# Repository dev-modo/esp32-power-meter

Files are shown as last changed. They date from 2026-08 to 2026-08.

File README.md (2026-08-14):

# ESP32 Power Meter

A complete home power-monitoring system: an **ESP32** reads a **PZEM-004T (100 A)** energy-meter module and pushes readings once a second to a small **Python (FastAPI) backend** running on your home server. A static **dashboard hosted on GitHub Pages** pulls the data from that backend and shows live values and history graphs for every metric.

```mermaid
flowchart LR
    PZEM[PZEM-004T 100A] -- "Modbus-RTU (UART)" --> ESP[ESP32]
    ESP -- "HTTP POST /api/ingest\nevery 1 s" --> API[FastAPI backend\nhome server :8000]
    API -- "SQLite" --> DB[(readings.db)]
    WEB[Dashboard\nGitHub Pages] -- "GET /api/latest\nGET /api/history\nGET /api/stats" --> API
```

## Repository layout

| Directory | What it is |
|---|---|
| [`firmware/`](firmware/) | ESP32 firmware (PlatformIO / Arduino IDE) — PZEM readings, WiFiManager pairing, status LED, reset button |
| [`server/`](server/) | Python FastAPI backend — receives readings, stores them in SQLite, serves the dashboard API (Docker Compose ready) |
| [`docs/`](docs/) | Static dashboard — served by GitHub Pages, shows live tiles + history charts for all metrics |
| [`enclosure/`](enclosure/) | 3D-printable box and screw-on lid (OpenSCAD source + ready-to-slice STLs) |

## Hardware

- ESP32 dev board (any common devkit)
- PZEM-004T **100 A** module (external CT coil version; Modbus-RTU protocol)
- 1 LED (status indicator — the onboard LED on GPIO 2 works out of the box)
- 1 push button (WiFi reset / pairing)

| PZEM-004T | ESP32 |
|---|---|
| TX | GPIO 16 (RX2) |
| RX | GPIO 17 (TX2) |
| VCC | 5 V (VIN) |
| GND | GND |

| Part | ESP32 |
|---|---|
| LED (+ 220 Ω to GND) | GPIO 2 |
| Push button (to GND) | GPIO 13 |

**LED codes:** fast blink = pairing portal open · medium blink = connecting to WiFi · solid = connected and server reachable · slow blink = WiFi OK but server unreachable.

**Button:** hold **5 seconds** to erase WiFi credentials and reboot into pairing mode (`PowerMeter-Setup` access point).

## Mains electricity — read before you build

This device connects to **230 V AC mains**. Mains voltage can kill you, and a
fault inside a badly built monitor can start a fire inside your wall.

**The 3D-printed enclosure in [`enclosure/`](enclosure/) is a bench and
prototyping housing. It is not a certified mains enclosure and must not be used
for a permanent, unattended installation.** Hobby filament has no UL 94
flammability rating, no tracking rating and no glow-wire rating. For anything
permanent, use an off-the-shelf ABS or PC IP65 junction box.

At minimum, if you build this:

- **Never print the enclosure in PLA** — PETG at minimum, V-0 rated ideally
- **Fuse the voltage tap**: inline 500 mA–1 A *ceramic* HRC fuse, 250 V AC, in
  the live sense lead; feed it from a fused spur or MCB way behind a 30 mA RCD
- Use a **PZEM-004T v3.0 or v4.0** — earlier revisions lack opto-isolated TTL
  and would put the ESP32 and its USB port at mains potential
- **Never connect USB while the mains side is live**, and flash the firmware
  with mains fully disconnected
- Use **cable glands**, not bare holes, and separate the mains and low-voltage
  sides inside the box
- The CT clamps **one conductor only**, never live and neutral together

Full detail in [`enclosure/README.md`](enclosure/README.md#mains-safety). If you
are not confident working with mains, have an electrician do the connection.

## Getting started

Set things up in this order:

### 1. Backend (home server)

```bash
cd server
cp .env.example .env   # set your API key
docker compose up -d
```

The API listens on port **8000**. See [`server/README.md`](server/README.md) — including the important **HTTPS / mixed-content** section: GitHub Pages is served over HTTPS, so the browser will only call your backend if it is also reachable over HTTPS (e.g. behind Nginx Proxy Manager with a DuckDNS domain and Let's Encrypt).

### 2. Firmware (ESP32)

Flash `firmware/` with PlatformIO or the Arduino IDE, then power up. The ESP32 opens a `PowerMeter-Setup` access point — join it, and in the portal pick your WiFi and enter the backend URL, API key, and device ID. Full walkthrough in [`firmware/README.md`](firmware/README.md).

### 3. Dashboard

The dashboard is published automatically from `docs/` via GitHub Pages. Open it, tap the gear icon, and enter your backend URL. Settings are stored locally in your browser.

## Try it without hardware

[`tools/mock_esp32.py`](tools/mock_esp32.py) simulates the whole device — a house with a fridge cycling, a kettle spiking, lights and AC switching on and off — and posts the exact same payload the firmware does. Stdlib only, no dependencies.

```bash
# Terminal 1 — the backend
cd server && API_KEY=demo-key-12345 \
  DB_PATH=./data/powermeter.db uvicorn main:app --port 8000

# Terminal 2 — seed 6 h of history, then stream live every 1 s
python3 tools/mock_esp32.py --backfill 6 --key demo-key-12345
```

Open `docs/index.html` (or the hosted dashboard) and point it at `http://localhost:8000`. About 1% of readings are sent as nulls on purpose, simulating a failed PZEM read, so the chart gap handling gets exercised too.

## Exposing a local backend

GitHub Pages is HTTPS, so the dashboard can only reach an HTTPS backend. To demo from a laptop, tunnel it:

```bash
# ngrok — needs a free account authtoken, one time
ngrok config add-authtoken YOUR_TOKEN
ngrok http 8000

# or Cloudflare quick tunnel — no account needed
cloudflared tunnel --url http://localhost:8000
```

Paste the resulting HTTPS URL into the dashboard's settings panel, or set `DEFAULT_BASE_URL` at the top of [`docs/app.js`](docs/app.js) to bake it in.

> Both of the above hand out a **random URL that changes on every restart**. For something permanent, use an ngrok static domain (one is included free), or a named Cloudflare tunnel on a domain you own. For a real always-on install, the intended setup is the backend on your home server behind a reverse proxy with a Let's Encrypt certificate — see [`server/README.md`](server/README.md).

## API overview

| Endpoint | Purpose |
|---|---|
| `POST /api/ingest` | ESP32 pushes a reading (voltage, current, power, energy, frequency, power factor, RSSI, uptime) |
| `GET /api/latest` | Most recent reading + online flag |
| `GET /api/history?minutes=&max_points=` | Downsampled time series for charts |
| `GET /api/stats?hours=` | Energy used, average/max power, voltage range over a window |
| `GET /api/health` | Health check |

## License

[MIT](LICENSE)

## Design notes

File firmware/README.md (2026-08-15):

# ESP32 Power Meter — Firmware

Firmware for an ESP32 devkit that reads a **PZEM-004T (100 A, Modbus-RTU)**
energy monitor every **second** and POSTs the readings as JSON to the
project's ingest server (`POST <server_url>/api/ingest`). WiFi and server
settings are configured through a captive pairing portal — no code edits or
reflashing needed to change networks or servers.

> **⚠️ Mains voltage warning:** the PZEM-004T's measurement side connects to
> live mains wiring. If you are not comfortable and qualified to work with
> mains voltage, get help from someone who is. Always kill the breaker before
> touching the high-voltage side.

## Wiring

The PZEM has **two electrically separate sides** at opposite ends of the board.
Only the 4-pin header touches the ESP32. The screw terminals are mains.

### Low-voltage side: the 4-pin header → ESP32

The header is labelled, in order, **GND · TX · RX · 5V**. Trust the silkscreen
text rather than counting pins — clone boards have been seen rotated.

| PZEM header | ESP32 | Notes |
|---|---|---|
| GND | GND | Mandatory. Without it the opto interface cannot work at all. |
| **TX** | **GPIO4** | ⚠️ Note the cross-over — PZEM *TX* goes to the ESP32 pin that *receives* |
| **RX** | **GPIO25** | ⚠️ PZEM *RX* goes to the ESP32 pin that *transmits* |
| 5V | **3V3** ← *not* 5V | See the box below. This pin only feeds the optocoupler LEDs. |

9600 baud, 8N1, Modbus-RTU.

> [!IMPORTANT]
> **The data pair crosses over. TX does not go to TX.**
>
> ```
>   PZEM  TX ──────────────╮   ╭────────── GPIO4   (ESP32 receives)
>                          ╰─╳─╯
>   PZEM  RX ──────────────╯   ╰────────── GPIO25  (ESP32 transmits)
> ```
>
> "TX" printed on a board always means *that board's* transmit pin, so the label
> is relative to whichever board you are reading. TX is a mouth, RX is an ear —
> each device's mouth has to point at the other's ear. Wiring TX→TX puts two
> mouths together and leaves both ears listening to each other.
>
> **Getting it wrong causes no damage**, it just means silence: every register
> reads `NAN` and the serial log prints `[pzem] no response`. Swap the two data
> wires and it works. Leave GND and the 3V3 supply alone.

Both data pins are named from the ESP32's side in the firmware — `PIN_UART_RX`
is the pin the *ESP32* receives on, so it connects to the PZEM's **TX**.

> [!WARNING]
> **Feed that header's "5V" pin from 3.3 V, not 5 V.** An earlier version of
> this file said to use 5 V and claimed no level shifter was needed. That
> combination is wrong and stresses the ESP32.
>
> The TTL section is nothing but a connector, four 1 kΩ resistors and two
> optocouplers — there is no regulator or level translation on it. The opto
> output is open-collector with **`R4`, a 1 kΩ pull-up to that header pin**, so
> whatever you feed it *becomes the logic level*. At 5 V the PZEM's TX idles at
> 5 V into a GPIO specified for 3.6 V max (ESP32 datasheet Table 5-3,
> V_IH max = VDD + 0.3). The RX line is worse than it looks: its opto LED is fed
> from the same pin through `R8` = 1 kΩ, so whenever GPIO25 is not actively
> pulling low — during reset, before `Serial2` is configured — RX floats to
> ~4.9 V, and the ESP32's internal 45 kΩ pull-down cannot fight a 1 kΩ pull-up.
> So at 5 V *both* pins are over-stressed.
>
> Many people run it at 5 V and report it working: the 1 kΩ limits injected
> current to ~1.4 mA, which parts often survive. That is survival, not
> compliance, and not what you want in a wall for years.
>
> **Powering it from 3.3 V makes both directions natively 3.3 V with no extra
> parts.** The only consequence is less optocoupler current — about 2.1 mA
> instead of 3.8 mA — still ample at 9600 baud, where one bit lasts 104 µs and
> the optocoupler switches in microseconds. If reads are unreliable, solder a
> second 1 kΩ across `R8` to restore ~4.2 mA.
>
> Two honest caveats. This is validated by the module schematic and widely used
> (ESPHome and Tasmota both document it), but it is **not a vendor-sanctioned
> mode** — Peacefair's manual only ever says "requires external 5V power supply"
> and never states a logic level. It fails *safe*: too little opto current gives
> `NAN` reads, never damage. And the board's TX/RX indicator LEDs go dim or dark
> at 3.3 V, so don't diagnose from them.
>
> **If you must use 5 V**, the fix is one resistor, not a level shifter: a
> **1.5 kΩ from the PZEM-TX / GPIO4 node to GND**, which forms a divider with the
> internal 1 kΩ `R4` and lands at 3.00 V. The other direction needs nothing —
> the ESP32's 3.3 V comfortably drives the PZEM's input.

### LED and button

| Peripheral | ESP32 | Notes |
|---|---|---|
| LED | GPIO2 → 220 Ω → LED **anode**; cathode → GND | Active-high. 220 Ω suits red/yellow/green; use 100 Ω for blue/white. The onboard LED on many devkits is already on GPIO2 with its own resistor. |
| Button | GPIO13, other leg → GND | `INPUT_PULLUP`, no external resistor |

GPIO2 is a **download-mode strapping pin**. Wire the LED active-high as above
and it is fine; wiring it active-low or adding a pull-up can break flashing. If
uploads ever turn flaky, disconnecting the GPIO2 LED is the first thing to try.

GPIO13 is also JTAG TCK, which matters only if you ever want hardware debugging
— you would need to unplug the button for that.

### Why GPIO4 / GPIO25 and not the usual GPIO16 / GPIO17

**GPIO16 and GPIO17 are wired to the PSRAM** on every ESP32-WROVER, on
`-N4R2`/`-N8R2`/`-N16R2` WROOM variants, and on PICO-D4. Espressif's DevKitC
guide is blunt: *"The pins GPIO16 and GPIO17 are available for use only on the
boards with the modules ESP32-WROOM and ESP32-SOLO-1. The boards with
ESP32-WROVER modules have the pins reserved for internal use."*

GPIO4 and GPIO25 are free on every variant, and are Espressif's own UART2
defaults from arduino-esp32 3.x onward — changed from 16/17 to *"avoid conflicts
with other peripherals."* The ESP32 routes UART through its GPIO matrix, so any
free pins work. If you have a plain WROOM-32 and prefer 16/17, they will work;
just change `PIN_UART_RX` / `PIN_UART_TX`.

### Powering it

**Use exactly one 5 V source for the ESP32** — either USB or an external supply
into 5V/VIN, never both at once. Some clone devkits omit the protection diode,
and back-feeding the USB rail can damage the board or the host.

### Using an ESP32-C3 instead

Supported — the firmware detects the chip and switches pins itself, so the same
source builds for both. **But the C3 is not a smaller ESP32**, and three facts
from the SDK force a different pinout:

- **`SOC_UART_NUM` is 2.** There is no `Serial2` at all, only `Serial0`/`Serial1`.
- **`SOC_GPIO_PIN_COUNT` is 22.** GPIO25 and GPIO13 simply do not exist.
- **GPIO2, GPIO8 and GPIO9 are strapping pins** (GPIO9 is the BOOT button on most
  devkits), and GPIO18/19 are the USB Serial/JTAG lines.

| | classic ESP32 | ESP32-C3 |
|---|---|---|
| PZEM **TX** → | GPIO4 | **GPIO4** |
| PZEM **RX** → | GPIO25 | **GPIO5** |
| LED | GPIO2 | **GPIO3** |
| Button | GPIO13 | **GPIO10** |
| UART | `Serial2` | `Serial1` |

The PZEM's GND and 3V3 connections are unchanged, and the data pair still
crosses over.

One practical difference: **a C3 devkit's onboard LED is an addressable RGB on
GPIO8**, not a plain one, so `digitalWrite` will not drive it. Wire your own LED
to GPIO3 as in the table.

Build it with `pio run -e esp32c3`, or pick **ESP32C3 Dev Module** in the Arduino
IDE (still set Partition Scheme to Minimal SPIFFS). Verified: **62% flash, 11%
RAM** — it fits comfortably, and uses *less* RAM than the classic ESP32 despite
having less to spare.

## LED status codes

| LED pattern | Meaning |
|---|---|
| Fast blink (150 ms) | Config/pairing portal is active |
| Medium blink (500 ms) | Connecting to WiFi |
| Solid ON | WiFi OK + server reachable |
| Slow blink (1200 ms) | WiFi OK, server unreachable (4+ consecutive failed POSTs)|
| 5 rapid flashes | Factory reset triggered, then reboot into the portal |

## Button

Hold the button for **5 seconds or more** to factory-reset: the LED flashes
5 times rapidly, the **WiFi credentials are erased**, and the device reboots
into the pairing portal. The **server URL, API key and device ID are kept**
in flash (NVS) and show up prefilled in the portal — you only need to pick a
WiFi network again.

## First boot / pairing

1. Power the ESP32. With no WiFi configured, the LED fast-blinks and the
   device opens an **open access point named `PowerMeter-Setup`**.
2. Join `PowerMeter-Setup` from your phone or laptop. A captive portal should
   pop up automatically; if not, browse to **http://192.168.4.1**.
3. Tap **Configure WiFi**, pick your network and enter its password.
4. Fill in the three extra fields:
   - **Server URL** — the **plain `http://` LAN address** of the backend, e.g.
     `http://192.168.1.8:8000`. See the note below — do not put the public
     HTTPS address here.
   - **API key** — leave empty unless the server was started with an `API_KEY`
   - **Device ID** — default `powermeter-01`; change it if you run several meters

> [!IMPORTANT]
> **The server URL is not in the firmware, and the ESP32 does not use the public
> HTTPS address.** Both of those surprise people, so:
>
> **It is not hardcoded** because it lives in NVS instead. You type it once into
> the pairing portal and it survives reboots, reflashes and even a WiFi factory
> reset — so you can move the server or change its port without rebuilding and
> reflashing the firmware.
>
> **It must be `http://`, not `https://`.** This firmware uses plain
> `HTTPClient` with no `WiFiClientSecure`, so it has no TLS at all. Given an
> `https://` URL it simply fails every POST, and the LED sits on the
> server-unreachable slow blink.
>
> That is deliberate, because **the backend has two different consumers with
> different needs**:
>
> | Who | URL | Why |
> |---|---|---|
> | **ESP32** | `http://192.168.1.8:8000` | Same LAN as the server. Talks straight to the container, skipping the reverse proxy. No TLS needed or wanted — it is local traffic, and TLS on an MCU costs flash, RAM and battery for nothing here. |
> | **Dashboard** (browser) | `https://powermeter.dilanp.duckdns.org` | Runs from GitHub Pages over HTTPS, from anywhere. Browsers block an HTTPS page calling a plain-HTTP backend, so this one *must* be TLS, which is what the reverse proxy provides. |
>
> Pointing the ESP32 at the public HTTPS name would also be a needless round
> trip: out to your router, back in through the proxy, to reach a box sitting on
> the same switch.
>
> To report from *outside* your LAN — a remote site on a phone hotspot — put the
> public `https://` URL here instead. The firmware does TLS now; see
> [Remote / cellular operation](#remote--cellular-operation) below, and note the
> interval floor, because data cost is the real constraint there.
5. Save. The device connects (medium blink), then goes **solid ON** once the
   server accepts data. Watch the serial monitor at **115200 baud** for logs.

Settings live in NVS namespace `powermeter`, so they survive reboots and
re-flashes.

## Reconnecting — it never gives up

Once a network has been saved, the firmware **retries it forever and will not
put itself back into pairing mode on its own.** This is deliberate: after a
power cut the router routinely takes a minute or two longer to boot than the
ESP32, and a meter that parks itself in a pairing portal until someone walks
over to it is useless.

| Situation | What happens |
|---|---|
| Saved network not up yet at boot | Retries every ~23 s **indefinitely**, LED medium-blinking. Never opens the portal. |
| WiFi drops while running | `setAutoReconnect` plus a `WiFi.reconnect()` nudge every 15 s, forever. |
| Router gone for a week | Keeps retrying; reconnects on its own when it returns. |
| Saved password no longer correct | Also retries forever — the serial log says `connect failed (wrong password?)` rather than "network not found", so the one user-fixable case is distinguishable. Hold the button to re-pair. |
| Server down but WiFi fine | Keeps posting; LED slow-blinks after 4 failures. Recovers on the first success. |
| No credentials saved (first boot / after reset) | Opens the portal and leaves it open with **no timeout** — there is nothing to retry. |

The only way into pairing mode is to ask for it: **hold the button 5 seconds.**
That works at any time, including while the device is stuck retrying at boot, so
you never need to power-cycle to get the portal back.

Making that guarantee real took some care, and it is the reason the retry loop
calls `WiFi.begin()` directly instead of `wm.autoConnect()`. `autoConnect()`
blocks for the whole connect timeout (~20 s against an absent router) without
reading the button, which left the escape hatch unusable precisely when it was
needed — and worse, a brief tap during that blind window could be mistaken for a
finished hold and wipe the credentials. The connect is now driven by a polled
loop that samples the button every 10 ms, and `handleButton()` additionally
refuses to act on a hold it did not observe continuously. Both directions are
covered by [`test/test_button_logic.py`](test/test_button_logic.py), which runs
on a laptop with no hardware:

```bash
python3 firmware/test/test_button_logic.py    # 12 passed, 0 failed
```

## Remote / cellular operation

The firmware speaks HTTPS, so the meter can live at a remote site on a phone
hotspot and report to the public endpoint. Put the `https://` URL in the portal
and it switches transport automatically.

**Data is the binding constraint, not bandwidth.** Neither ESP32 core supports
TLS session resumption, so any POST on a fresh connection pays a full handshake —
about 4.3 KB, measured against the live server, versus ~700 bytes for the reading
itself. Keep-alive amortises that while the connection survives, but cellular NAT
drops idle connections regularly.

| Interval | Roughly per month |
|---|---|
| 1 s | **~16 GB** — would destroy a phone plan |
| 10 s | ~1.6 GB |
| **30 s** | **~530 MB** — recommended for cellular |
| 60 s | ~265 MB |

So the portal has a **Report interval** field, and the firmware enforces a floor
that follows the transport: **1 s on `http://`**, **10 s on `https://`**. The
clamp is applied at send time, not at save time — move the same device from your
LAN to the remote URL and its cadence backs off on its own. You cannot
accidentally leave it hammering a metered link once a second.

The device reports its own cadence to the server, which sizes the "online" window
from it (3 missed reports + 10 s, floored at 30 s) instead of assuming 10 s. The
dashboard likewise polls at half the device's rate rather than once a second, and
stops entirely while its tab is hidden.

### Things that bite specifically on a hotspot

- **iPhone Personal Hotspot is 5 GHz-only unless "Maximize Compatibility" is on.**
  The ESP32 is 2.4 GHz only, so it will never see the network. Turn that on
  *before* you debug anything else.
- **Certificate validation does not need a clock.** Both cores ship mbedTLS with
  `MBEDTLS_HAVE_TIME_DATE` disabled, so the usual "NTP first or TLS fails" trap
  does not apply — verified in both cores' sdkconfigs. Signature-chain and
  hostname checks still run; only expiry is skipped.
- **The server must keep TLS 1.2 enabled.** Neither core has a TLS 1.3 client, so
  hardening the proxy to 1.3-only would silently kill the device.
- **Two root CAs are embedded**, ISRG Root X1 and X2. Either validates the chain
  today, but each fails in a different future — X1 alone breaks if Let's Encrypt
  stops sending the X2 cross-sign, X2 alone breaks if the cert is re-issued as
  RSA. Both together cost ~2.7 KB.

## Reporting

Every **second** the firmware reads voltage, current, power, cumulative
energy (kWh), frequency and power factor from the PZEM and POSTs them to
`<server_url>/api/ingest` with the `X-API-Key` header (only when a key is
set). Failed sensor reads are sent as JSON `null`. Example payload:

```json
{
  "device_id": "powermeter-01",
  "voltage": 231.2,
  "current": 1.234,
  "power": 285.1,
  "energy": 12.345,
  "frequency": 50.0,
  "pf": 0.95,
  "rssi": -61,
  "uptime_s": 12345
}
```

## Flashing

### Option A — PlatformIO (recommended)

```sh
cd firmware
pio run                  # build
pio run -t upload        # flash (auto-detects the serial port)
pio device monitor       # serial logs at 115200 baud
```

The `esp32dev` environment in `platformio.ini` pulls in all three libraries
automatically.

### Option B — Arduino IDE

1. Install the **ESP32 board package** (Boards Manager → search "esp32" by
   Espressif) and select the board **ESP32 Dev Module**.
2. Install these libraries via **Sketch → Include Library → Manage Libraries**:
   - **WiFiManager** by *tzapu* (2.x)
   - **PZEM004Tv30** by *Jakub Mandula* (1.2.1 or later) — search for
     `PZEM004Tv30`, spelled exactly like that. The GitHub repo and the
     PlatformIO registry call it `PZEM-004T-v30`, but the Arduino Library
     Manager has no entry under that name.
   - **ArduinoJson** by *Benoit Blanchon* (7.x)
3. Set **Tools → Partition Scheme → "Minimal SPIFFS (1.9MB APP with OTA)"**.
   WiFiManager's captive portal is large: on the default 1.2 MB app partition
   the build lands at **89% full**, which works but leaves no headroom. Minimal
   SPIFFS drops it to ~59%. This firmware keeps everything in NVS and never
   uses SPIFFS, so nothing is lost. (PlatformIO does this automatically via
   `board_build.partitions` in `platformio.ini`.)
4. Create a sketch folder named e.g. `PowerMeter`, copy `src/main.cpp` into it
   and rename it `PowerMeter.ino`. (The `#include <Arduino.h>` at the top is
   harmless in the IDE.)
5. Set the serial monitor to **115200 baud**, pick your port, and Upload.

### Verified builds

This firmware is confirmed to compile — not merely reviewed — on **both**
toolchains and, usefully, on **both ESP32 Arduino core generations**. Plenty of
ESP32 sketches break between core 2.x and 3.x; this one builds on each:

| Toolchain | ESP32 core | Flash (min_spiffs) | RAM |
|---|---|---|---|
| PlatformIO 6.1.19, Espressif32 7.0.1 | 2.0.17 | 1 043 665 B — **53.1%** | 14.7% |
| arduino-cli 1.5.1 | 3.3.10 | 1 166 616 B — **59%** | 15% |

Libraries resolved: WiFiManager 2.0.17, ArduinoJson 7.4.3, and the PZEM library
at 1.1.2 (PlatformIO) / 1.2.1 (Arduino) — plus `WiFi`, `HTTPClient`,
`Preferences` and `Ticker` from the core.

Zero compiler warnings from this code at `--warnings all`. WiFiManager emits a
few `-Wformat` warnings from its own source; those are upstream, not ours.

On the **stock 1.2 MB partition** the same binary sits at **89%** full — it
flashes and runs, but leaves nothing spare, which is why `min_spiffs` is the
configured default.

## Troubleshooting

- **All readings `null` / "no response" in the log** — in rough order of
  likelihood: TX/RX swapped (PZEM TX must go to **GPIO4**); the 4-pin header's
  GND not connected (all four pins are required); the header unpowered; or you
  are on a WROVER/PSRAM board still wired to GPIO16/17. Note the PZEM only
  measures when its **mains side is live** — a bench-powered module with no
  mains reports nothing, which looks identical to a wiring fault.
- **Voltage reads fine but current sits at 0.00 A** — the CT is almost certainly
  clamped around **both** live and neutral, so the two currents cancel. It must
  go around one conductor only. Also check the split core is fully latched
  closed; anything below the 0.02 A starting current reads as zero.
- **Slow LED blink** — the ESP32 has WiFi but can't reach the server: check
  the server URL (including the `:8000` port), that the server is running,
  and the API key. Exact HTTP errors are printed on the serial monitor.
- **Stuck at medium blink** — wrong WiFi password or network out of range.
  Hold the button 5 s to reopen the pairing portal.

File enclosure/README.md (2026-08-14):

# Enclosure

A 3D-printable box with a screw-on lid for the power meter.

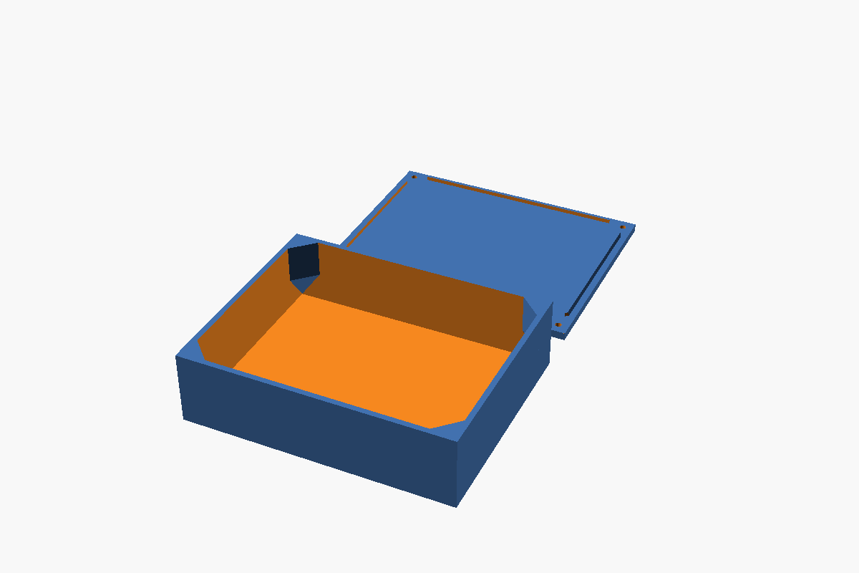
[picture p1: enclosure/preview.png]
Box and lid


| | |
|---|---|
| **Outside** | 100 × 80 × 30 mm |
| **Inside** | 96 × 76 × 25 mm |
| **Walls / floor / lid** | 2 mm / 2 mm / 3 mm |
| **Fixings** | 4 × M2 self-tapping screws, 12 mm (one per corner) |
| **Openings** | **none at all in the box** — not even screw pilots. Drill to suit. |
| **Supports** | none, either part |

> [!WARNING]
> **Read [Mains safety](#mains-safety) before you put this near mains wiring.**
> This is a bench and prototyping housing. It is not a certified mains
> enclosure, and **PLA must not be used for it.**

## Files

| File | What it is |
|---|---|
| [`enclosure.scad`](enclosure.scad) | The parametric source. Everything is a named variable at the top. |
| `box.stl` / `lid.stl` | Ready to slice, generated from the defaults. |
| [`test_variants.sh`](test_variants.sh) | Renders every optional configuration and checks each is still watertight. |

Re-export after changing anything:

```bash
openscad -D 'part="box"' -o box.stl enclosure.scad
openscad -D 'part="lid"' -o lid.stl enclosure.scad
./test_variants.sh          # 14 configurations, all must report manifold
```

## Will your boards fit?

Yes, but **lay them out lengthwise** — that is the one constraint at this size.
Side by side with their long axes along the 96 mm direction:

```
  PZEM-004T   74 x 31 mm   |   ESP32 devkit   55 x 28 mm

  31 + 28 = 59 mm across the 76 mm width   ->  17 mm spare
  longest board 74 mm along the 96 mm length  ->  fits
```

Turned the other way, the PZEM's 74 mm length would have only 76 mm to sit in,
leaving nothing for the ESP32 beside it.

**On height, the PZEM sets the floor**, and it is why this cannot be a 20 mm box.
Its 5.08 mm-pitch screw terminals stand 10.0 mm above the PCB:

```
  5.0 mm   M3 nylon standoff (clears the terminal's 3.7 mm pins underneath)
+ 1.6 mm   PCB
+ 10.0 mm  screw terminal block
= 16.6 mm  — a 20 mm box gives a 16 mm cavity, so it does not close
```

At 30 mm the cavity is 25 mm, leaving **8.4 mm of headroom** for wiring above the
terminals. Some vendors list the whole module at 16–18 mm tall, so if yours is one
of those, put a caliper on it before printing.

Using different hardware? Measure it and set the three `outer_` values —
everything else derives from them, and the file prints a warning if the cavity
drops below 22 mm.

## Screws

**4 × M2 self-tapping, 12 mm** — one per corner. With the 3 mm lid that gives
about 9 mm of thread engagement.

They do not thread into cylindrical posts. Each corner is filled with a **45°
gusset** running 12 mm along both walls, so the screw material *is* the corner.
It reads as part of the shell rather than a cylinder stuck onto it, and there is
no thin post-to-wall junction to crack along. The lid's locating lip is cut back
around each gusset so it never fouls them.

The gussets are also **kept as small as the job allows**, because a full-height
prism in each corner is mostly plastic doing nothing:

- M2 needs far less meat than M3. At 12 mm with the screw 4 mm in, there is
  1.95 mm of material around the pilot out to the diagonal face — above the
  ~1.5 mm that thread-forming into plastic wants. Any smaller and the diagonal
  starts cutting into the hole.
- The screw only engages the top 10 mm, so the gusset is full size for the top
  14 mm and then **tapers down** to a 4 mm footprint at the floor.

Measured off the rendered STLs at this size, that takes the four gussets from
**7.20 cm³ to 2.26 cm³ — a 69% cut**, 4.9 cm³ of filament, about 12% of the whole
box. The
taper still needs no supports: its downward faces sit 66.5° off straight-down,
comfortably clear of the 45° limit, and `test_variants.sh` asserts no facet in
either part falls below that.

### Drilling the pilots

**The box prints with no screw holes** — the gussets are left solid. Use the lid
as a drill template:

1. Sit the lid on the box, lined up with the outside edges.
2. Drill down through the lid's four clearance holes into the gussets.
3. Aim for about 10 mm deep — that stays inside the full-size top section of the
   gusset. A hand drill is plenty.

Doing it this way means the two parts physically cannot end up misaligned, which
is the usual failure with pre-modelled holes and a slightly shrunk print.

Prefer them modelled? Set `pilot_holes = true`.

Four screws were a concern at the original 150 × 100 size, where the lid spanned
146 mm unsupported and a 3 mm plate bowed about half a millimetre mid-edge. **At
96 × 76 that worry mostly goes away** — plate deflection scales with the fourth
power of the span, so shrinking it to 96 mm cuts the bow to under a fifth of that,
around 0.1 mm. Corner-only fixing is genuinely fine here.

If you ever scale the box back up and the seam starts showing a gap mid-span,
raise `lid_t` to 4 or uncomment the mid-wall positions in `screw_xy()` (they would
need their own bosses, since the gussets only cover corners).

Use a **slightly bigger bit than the textbook 1.6 mm** for M2. In moulded plastic
1.6 is right; in a printed part a tight pilot splits the material on first
assembly, because the layers give it a plane to split along.

| Material | Pilot |
|---|---|
| PLA | 1.8 mm |
| PETG / ABS / ASA | 1.7 mm |
| Nylon | 1.6 mm |

Hand-tighten only — roughly **0.1 Nm**, which is not much; M2 threads in plastic
strip easily. Use a hex or Torx driver rather than a Phillips, which cams out and
tempts you to lean on it, and never a power driver. If the box will be opened
often, use **M2 heat-set brass inserts** instead (typically 3.2 mm OD × 4 mm) —
set `screw_pilot_d` to the insert bore and drill for that. The gussets have the
material for it without any other change.

## Printing

Both parts sit flat on the bed and need **no supports**.

> The lid is modelled lip-**up**, which is how it must print. Do not flip it
> lip-down — that suspends the whole 100 × 80 plate over the lip and needs
> full supports. Want a nicer outer face? Use a textured build plate.

| Setting | Value |
|---|---|
| Layer height | 0.2 mm (0.25 mm first layer, 20 mm/s) |
| Wall extrusion width | 0.50 mm |
| Wall loops | **5** for the box, 4 for the lid |
| Top / bottom solid layers | 5 / 4 |
| Infill | irrelevant — nothing in either part has any |
| Supports | off |
| Brim | 3 mm on the lid (cheap insurance); 5 mm for ABS |
| Seam position | aligned or rear, so it misses the lip's mating face |

Wall loops matter more than they look: at 4 × 0.50 mm the 2 mm wall comes out as
one continuous solid. Leave the default 0.45 mm width and you get gap-fill and a
sliver of infill inside a wall that should be solid.

The 100 × 80 mm footprint fits every common printer, including a Bambu A1 mini
(180²), which the earlier 150 × 100 version did not.

If the lid binds, increase `lip_clear` (0.45 default, try 0.6). It tapers inward
as it rises so it self-centres, which forgives a little wall bow.

## Cable entries

**The box prints sealed — there are no openings.** Drill your own once the boards
are positioned: with only 2 mm of wall a hand drill or a reamer cuts one in
seconds, and you get to put it exactly where the cable actually lands instead of
where a model guessed.

If you would rather model them, `holes_x0` and `holes_x1` take
`[y_position, diameter, z_centre]` and cut through the short ends. Two things to
get right. **Size for a gland, not for the cable** — 3-core 1.5 mm² mains flex is
8.1 mm across, so it would not even pass an 8 mm hole, and 8 mm matches no gland
thread made. And **a bare printed hole is not strain relief**: a tug on the cable
goes straight to the screw terminal.

| Gland | Hole | Cable range |
|---|---|---|
| PG7 / M12×1.5 | 12.5 mm | 3–6.5 mm |
| PG9 | 15.2 mm | 4–8 mm |
| M16×1.5 | 16.2 mm | 4–8 mm |
| PG11 | 18.6 mm | 5–10 mm |
| M20×1.5 | 20.2 mm | 6–12 mm |

Heights are per hole rather than auto-centred, so a USB opening stays aligned to
the actual connector instead of drifting whenever `outer_z` changes. Two helper
values are defined for it: `mid_z` (vertical centre of the cavity) and `usb_z`
(a micro-USB port on a board sitting on 8 mm standoffs).

## Mounting your boards

`standoffs` is **empty by default** and that is deliberate — hole spacing varies
between PZEM-004T and ESP32 board revisions, and a standoff in the wrong place is
worse than none. Measure yours, then fill in `[x, y, height, outer_d, pilot_d]`.

One trap: an ESP32 devkit with its male headers still fitted has about **6 mm of
pin sticking out below the PCB**, so it needs a standoff of at least 7–8 mm. The
obvious 4 mm jams the pins into the floor.

`mount_ears = true` adds external wall-mounting tabs (this grows the footprint to
100 × 100). Never screw through the bare floor instead — it breaches the
enclosure and cracks the 2 mm base.

## Mains safety

The PZEM measures mains voltage, so live conductors enter this box. A review of
this design flagged the following, and the honest summary is:

**Use this printed box for bench work and prototyping. For a permanent,
unattended installation, put the electronics in an off-the-shelf ABS or PC
IP65 junction box** (UL 94 V-0, 960 °C glow-wire, moulded gland entries) — one
costs less than the filament, and the printed part can be reduced to an internal
mounting tray if you like.

If you do build it in plastic you printed yourself:

- **Never PLA.** Glass transition around 60 °C and it creeps under sustained
  screw preload. **PETG at minimum**; ABS/ASA is better; a UL 94 V-0 rated
  filament (PETG-FR, ABS-FR, PC-FR) is what the job actually calls for. Hobby
  filament carries no flammability, tracking or glow-wire rating at all.
- **Fuse the voltage tap.** An inline 500 mA–1 A **ceramic** HRC fuse, 250 V AC,
  in the live sense lead, as close to the tap as possible, in an enclosed
  holder. Ceramic specifically — a glass fuse lacks the breaking capacity. Feed
  from a fused spur or a 2 A MCB way, on a circuit behind a 30 mA RCD.
- **Separate mains from low voltage.** Set `divider = true` for a full-height
  barrier between the PZEM's terminals and the ESP32/LED/button, with a notch
  at the far edge for the UART wires. An undivided cavity puts live terminals in
  the same space as parts you can touch.
- **Use glands, not holes**, and add a slack loop inside so a tug on the cable
  cannot reach the terminal.
- **PZEM v3.0 or v4.0 only.** Older revisions lack opto-isolated TTL, which
  would put the ESP32 and its USB port at mains potential. Even on v3.0/v4.0 the
  isolation is *functional*, not safety-rated: never touch the ESP32, LED or
  button while mains is connected, and **never plug in USB while the mains side
  is live.** Flash and debug with mains fully disconnected.
- **Keep every metal part inaccessible.** The screw shafts pass into the cavity.
  Use nylon M2 screws, or raise `lid_t` to 3.5, enable `lid_counterbore` and plug
  the recesses. Plastic-bodied button and LED bezel, both on the low-voltage
  side. Nylon glands. This is a Class II design — do not try to earth a printed
  box.
- **Fix the boards down.** Nothing should be able to shift onto a live terminal.
  Keep `tie_slots = false` for any mains build; it pierces the floor.
- **The CT clamps one conductor only**, never live and neutral together. Do not
  open the clamp or unplug its lead while the conductor is carrying current.
- **Wall thickness.** For a mains build set `wall = 3` and `floor_t = 3`.

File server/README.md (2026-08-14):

# ESP32 Power Meter — API Server

A small FastAPI + SQLite backend that sits between the ESP32 power meter
(which pushes a reading once a second) and the dashboard hosted on
GitHub Pages (which polls the read endpoints). No external database, no
accounts — one Python file and one SQLite file.

```
ESP32 ──POST /api/ingest──▶  this server  ◀──GET /api/latest|history|stats── dashboard (GitHub Pages)
```

---

## ⚠️ HTTPS / mixed content — read this before wiring up the dashboard

The dashboard is served from GitHub Pages over **https**. Browsers refuse to
let an https page call a plain **http** API ("mixed content") — the requests
are silently blocked and the dashboard will just show "offline", with errors
only visible in the browser console.

**You must expose this API over https** and use that https URL in the
dashboard settings. The usual home-server recipe:

1. **Get a domain** — e.g. a free [DuckDNS](https://www.duckdns.org)
   subdomain pointed at your public IP (or use a Cloudflare Tunnel /
   Tailscale Funnel if you don't want to open ports).
2. **Put a reverse proxy with TLS in front of the API** — e.g.
   [Nginx Proxy Manager](https://nginxproxymanager.com):
   * add a Proxy Host: `powermeter.yourname.duckdns.org` → forward to this
     container (`powermeter-api`, port `8000`, scheme `http`),
   * on the SSL tab, request a **Let's Encrypt** certificate (DuckDNS
     supports the DNS challenge, so this works even without opening port 80),
   * enable "Force SSL".
3. **Use the https URL** in both places:
   * dashboard settings → API base URL: `https://powermeter.yourname.duckdns.org`
   * ESP32 config portal → server URL (the ESP32 doesn't care about mixed
     content, but reusing the same URL keeps things simple).
4. **Set an `API_KEY`** (see below) — once the API is reachable from the
   internet, you don't want strangers pushing fake readings.

If you only ever open the dashboard from `http://localhost` or run it
locally, plain http works fine — the restriction comes from the browser,
not from this server.

---

## Run with Docker Compose (recommended)

```bash
cd server
cp .env.example .env   # optional: set API_KEY etc. (stack starts without it too)
docker compose up -d --build
curl http://localhost:8000/api/health   # -> {"status":"ok"}
```

The SQLite database is persisted in `./data/powermeter.db` on the host, so
`docker compose down` / image rebuilds never lose your readings.

> Note: the compose file marks `.env` as optional, which needs Docker
> Compose **v2.24+**. On older versions, either create the `.env` file or
> delete the `env_file:` block and put the variables under `environment:`.

## Run with a plain Python venv

```bash
cd server
python3 -m venv .venv
source .venv/bin/activate
pip install -r requirements.txt

# optional configuration:
export API_KEY=change-me
export RETENTION_DAYS=90

uvicorn main:app --host 0.0.0.0 --port 8000
```

The database is created at `./data/powermeter.db` (override with `DB_PATH`).

## Environment variables

| Variable | Default | Description |
| --- | --- | --- |
| `API_KEY` | *(unset — auth off)* | If set, `POST /api/ingest` requires a matching `X-API-Key` header, otherwise it answers `401`. |
| `CORS_ORIGINS` | `*` | Comma-separated list of allowed browser origins, e.g. `https://yourname.github.io`. `*` = allow all. |
| `RETENTION_DAYS` | `90` | Hourly cleanup deletes readings older than this many days. `0` disables cleanup (keep forever). |
| `DB_PATH` | `./data/powermeter.db` | SQLite file path. The compose file sets it to `/app/data/powermeter.db` (mounted volume). |

## API reference

All request and response bodies are JSON. Default port: **8000**.

### `POST /api/ingest` — ESP32 pushes one reading

Headers: `Content-Type: application/json`, plus `X-API-Key: <key>` when the
server has `API_KEY` set. The timestamp is assigned **server-side** at
receive time. Any metric may be `null` if the PZEM read failed.

```bash
curl -X POST http://localhost:8000/api/ingest \
  -H 'Content-Type: application/json' \
  -H 'X-API-Key: change-me' \
  -d '{"device_id":"powermeter-01","voltage":231.2,"current":1.234,"power":285.1,"energy":12.345,"frequency":50.0,"pf":0.95,"rssi":-61,"uptime_s":12345}'
```

Responses: `200 {"ok": true}` · `401` wrong/missing key · `422` malformed body.

### `GET /api/latest[?device_id=]` — newest reading

```json
{
  "device_id": "powermeter-01", "ts": 1765352410.5,
  "voltage": 231.2, "current": 1.234, "power": 285.1, "energy": 12.345,
  "frequency": 50.0, "pf": 0.95, "rssi": -61, "uptime_s": 12345,
  "age_s": 1.7, "online": true
}
```

`ts` is unix seconds (float, server receive time); `online` is
`age_s < 10`. Returns `404 {"detail":"no data"}` while the database is empty.

### `GET /api/history?minutes=60&max_points=500[&device_id=]` — chart data

* `minutes`: window length, default `60` (1 … 44640, i.e. up to 31 days)
* `max_points`: downsampling cap, default `500` (10 … 5000)

Returns `{"points":[{"ts","voltage","current","power","energy","frequency","pf"}, ...]}`
in ascending `ts`, bucket-downsampled to at most `max_points` points
(per-bucket average; `energy` uses the bucket maximum because it is a
cumulative counter).

### `GET /api/stats?hours=24[&device_id=]` — summary statistics

* `hours`: window length, default `24` (1 … 8760, i.e. up to a year)

```json
{
  "hours": 24, "samples": 43128,
  "energy_kwh": 6.42, "avg_power": 267.5, "max_power": 2140.0,
  "min_voltage": 224.1, "max_voltage": 236.8,
  "first_ts": 1765266010.1, "last_ts": 1765352410.5
}
```

`energy_kwh` is `max(energy) - min(energy)` over the window (delta of the
cumulative counter, clamped at ≥ 0 in case the counter was reset). Fields
are `null` when there is no data in the window.

### `GET /api/health` — liveness check

Returns `200 {"status":"ok"}`. Handy for Docker healthchecks and uptime
monitors.

## Data & retention

* One reading every second ≈ **86 400 rows/day/device**. Measured on a real
  database this table costs ~85 bytes/row including its indexes, so budget
  roughly **7 MB/day, 220 MB/month, and 0.65 GB at the default 90-day
  retention**. Fine on any home server, but plan the disk — this is the main
  cost of the 1-second cadence, and it is why the retention job exists.
* To cut that down, either raise `REPORT_INTERVAL_MS` in the firmware (2 s
  halves everything) or lower `RETENTION_DAYS`. The charts read from the
  downsampled `/api/history` endpoint, so a coarser cadence costs you nothing
  visually beyond the very shortest time ranges.
* An hourly background task deletes rows older than `RETENTION_DAYS`.
* Back up the meter history by copying `./data/powermeter.db`
  (stop the container first, or use `sqlite3 powermeter.db ".backup ..."`).

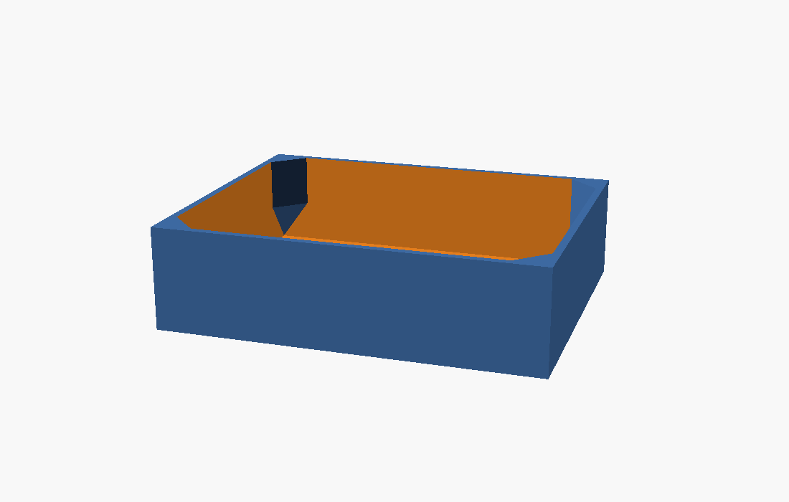
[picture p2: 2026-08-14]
enclosure/preview_gusset.png

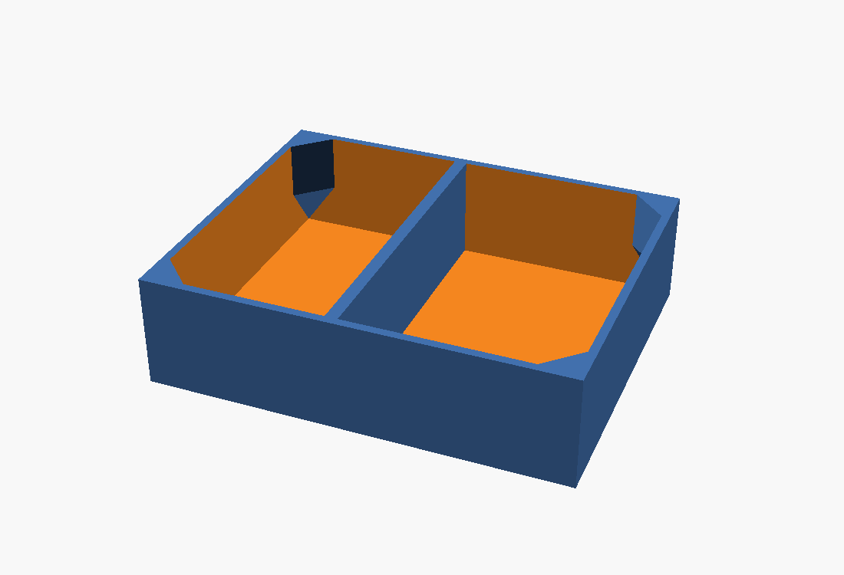
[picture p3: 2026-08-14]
enclosure/preview_divider.png

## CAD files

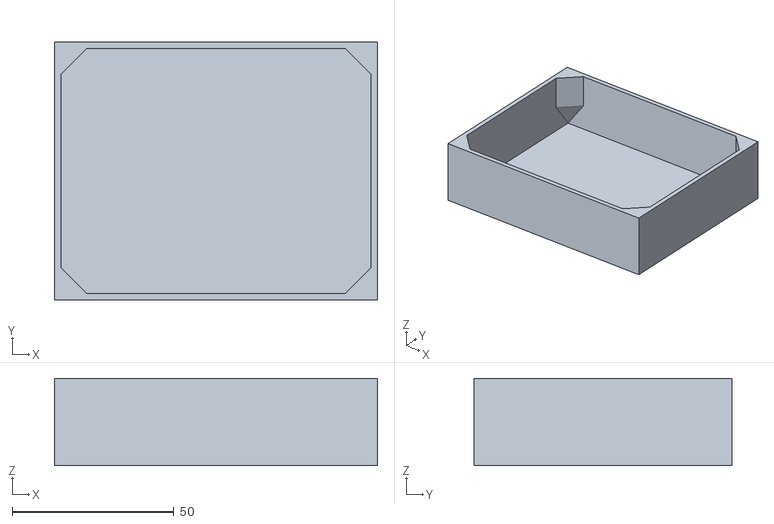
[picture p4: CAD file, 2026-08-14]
enclosure/box.stl
100.0 x 80.0 x 27.0

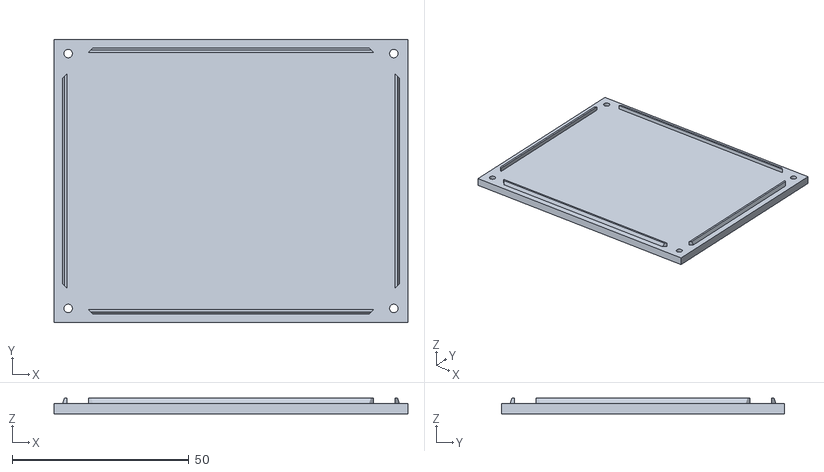
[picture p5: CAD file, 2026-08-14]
enclosure/lid.stl
100.0 x 80.0 x 4.50

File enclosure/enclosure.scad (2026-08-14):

/* ============================================================================
   ESP32 Power Meter — enclosure
   Parametric box + screw-on lid for OpenSCAD.

   Render / export:
     openscad -D 'part="box"' -o box.stl enclosure.scad
     openscad -D 'part="lid"' -o lid.stl enclosure.scad
   Open the file and press F5 to see both laid out side by side.

   Both parts print flat on the bed with NO SUPPORTS. See PRINTING below for
   the one orientation rule that matters.

   ---------------------------------------------------------------------------
   SIZE: 100 x 80 x 30 mm outside, giving a 96 x 76 x 25 mm cavity
   ---------------------------------------------------------------------------
   Both boards fit, but only in one orientation. Lay them side by side with
   their long axes along the 96 mm direction:

       PZEM-004T   74 x 31 mm  |  ESP32 devkit  55 x 28 mm
       31 + 28 = 59 mm across the 76 mm width -> 17 mm spare
       longest board 74 mm along the 96 mm length -> fits

   Turned the other way the PZEM's 74 mm length would have only 76 mm to sit
   in, which leaves nothing for the ESP32 beside it. So: lengthwise.

   On height, the PZEM is what sets the floor. Its 5.08 mm-pitch screw
   terminals stand 10.0 mm above the PCB, so the stack is

       5.0 mm standoff + 1.6 mm PCB + 10.0 mm terminal block = 16.6 mm

   which is why this cannot be a 20 mm box: that would leave a 16 mm cavity,
   over budget before a single wire is routed. At 30 mm the cavity is 25 mm,
   leaving 8.4 mm of headroom for wiring above the terminals.

   Using different hardware? Measure it and set the three outer_ values —
   everything else derives from them.
   ========================================================================= */

// ----------------------------------------------------------------- parts ----
// "box", "lid", or "both" (both = preview layout only, do not export it)
part = "both";

// ------------------------------------------------------------ dimensions ----
outer_x   = 100;  // length, outside
outer_y   = 80;   // width, outside
outer_z   = 30;   // TOTAL height including the lid — see note above
wall      = 2;    // side wall thickness  (use 3 for a mains build)
floor_t   = 2;    // base thickness       (use 3 for a mains build)
lid_t     = 3;    // lid thickness — 3 not 2, see the lid stiffness note

// Derived. box + lid == outer_z, so the lid never adds height on top.
box_h     = outer_z - lid_t;
cav_x     = outer_x - 2 * wall;
cav_y     = outer_y - 2 * wall;
cav_z     = box_h - floor_t;      // usable internal height

// Shout if the cavity gets too shallow for the hardware this project uses.
// echo() rather than assert() so you can still build a deliberately small box.
CAV_Z_MIN = 22;
if (cav_z < CAV_Z_MIN)
  echo(str("WARNING: internal height is only ", cav_z,
           " mm. A PZEM-004T needs ~17 mm before wiring. Raise outer_z to at least ",
           CAV_Z_MIN + floor_t + lid_t, "."));

// ----------------------------------------------------------------- screws ---
// M3 thread-forming screws, 12 mm long, into printed bosses.
// PILOT SIZE MATTERS: 2.5 mm is the textbook figure for M3 but it splits
// printed PLA bosses on first assembly. 2.7 is a safe middle ground.
//   PLA 2.8   |   PETG / ABS / ASA 2.6   |   nylon 2.4
// Better still, use M3 heat-set brass inserts (4.6 mm OD): set screw_pilot_d
// to your insert's bore (typically 4.0) and boss_d to 9.
// M2, 12 mm long. With a 3 mm lid that leaves ~9 mm of thread engagement.
screw_free_d  = 2.4;   // M2 clearance hole through the lid (medium fit)
screw_inset   = 4;     // screw centre, in from both outer faces

// The BOX prints with no holes at all — the corner gussets are left solid and
// you drill the pilots yourself. Do it with the lid as a template: sit the lid
// on the box, drill down through its clearance holes into the gussets, and the
// two parts cannot end up misaligned. Drill 1.8 mm in PLA, 1.7 in PETG/ABS/ASA.
// Set this true if you would rather have them modelled.
pilot_holes   = false;
screw_pilot_d = 1.75;  // only used when pilot_holes = true
screw_depth   = 10;    // ditto — stays inside gusset_top_h, see below

/* ---------------------------------------------------------------------------
   Corner gussets — the screws land in these, not in cylindrical posts.
   Each corner is filled with a 45-degree gusset running gusset_l along both
   walls, so the screw material IS the corner: continuous with the shell, with
   no thin post-to-wall junction to crack along.

   Sized for M2 and trimmed to stop wasting plastic. Two things shrink it:

   1. Footprint. M2 needs much less meat than M3 around the hole. At
      gusset_l = 12 with the screw 4 mm in, there is 2.8 mm from the hole
      centre to the diagonal face, so ~1.95 mm of material around a 1.75 mm
      pilot — comfortably above the ~1.5 mm minimum for thread-forming into
      plastic. Shrink it further and the diagonal starts cutting into the hole.

   2. Height. The screw only engages the top 10 mm, so a full-height prism is
      mostly dead weight. The gusset is full size for the top gusset_top_h and
      then tapers down to gusset_l_base at the floor.

   Measured off the rendered STLs at the default size, the four gussets cost
   2.26 cm3 rather than the 7.20 cm3 an M3-sized full-height version would —
   a 69% cut, 4.9 cm3 of filament, about 12% of the whole box.

   The taper still needs no supports: its downward faces sit 66.5 degrees off
   straight-down, well clear of the 45 degrees FDM needs, and the whole box
   contains no facet below that. If you change gusset_top_h or gusset_l_base,
   keep (cav_z - gusset_top_h) larger than (gusset_l - gusset_l_base) / 1.41
   or the underside turns into an overhang.
   ------------------------------------------------------------------------- */
gusset_l      = 12;   // leg length at the top, where the screw is
gusset_top_h  = 14;   // height of the full-size section, measured down from the rim
gusset_l_base = 4;    // leg length where it meets the floor

// Countersink the lid holes so the heads sit flush? Sized for an M2 pan head
// (~4 mm across, ~1.3 mm tall). Needs lid_t >= 3.5 to leave material behind the
// head, so it is off at lid_t = 3. With it off, use pan-head screws and let them
// stand proud — mechanically fine, and they only stand ~1.3 mm high at M2.
lid_counterbore    = false;
lid_counterbore_d  = 4.2;
lid_counterbore_h  = 1.4;

// ------------------------------------------------------------------- lid ----
// A shallow lip on the underside that drops into the opening: it locates the
// lid while you start the screws and closes the seam against dust.
lid_lip       = true;
lip_h         = 1.5;   // how far it protrudes into the box
lip_w         = 1.2;   // its wall thickness
// 0.45, not 0.3. An FDM wall bulges inward and a lip bulges outward; at 0.3 the
// two cancel and the lip binds. 0.5 if your XY compensation is uncalibrated.
lip_clear     = 0.45;
lip_taper     = 0.5;   // outer face narrows going up, so the lip self-centres

// ---------------------------------------------------------- cable entries ---
// EMPTY: the box prints fully sealed. Drill your own entries once the boards are
// positioned — with only 2 mm of wall a hand-held drill cleans a hole in
// seconds, and you get to put it exactly where the cable actually lands.
//
// To model them instead, add entries as [y_position, diameter, z_centre].
// Size them for a cable gland, not for the bare cable: 3-core 1.5 mm2 mains
// flex is 8.1 mm across and a bare printed hole is not strain relief.
//   PG7 / M12 = 12.5 mm   PG9 = 15.2   M16 = 16.2   PG11 = 18.6   M20 = 20.2
// z is explicit per hole rather than auto-centred, so a USB opening stays put
// instead of drifting whenever outer_z changes.
//   mid_z = vertical centre of the cavity
//   usb_z = centre of a micro-USB port on a board sitting on 8 mm standoffs
mid_z    = floor_t + cav_z / 2;
usb_z    = floor_t + 8 + 1.6 + 1.3;

holes_x0 = [];   // left end   e.g. [[ 30, 12.5, mid_z ]]
holes_x1 = [];   // right end  e.g. [[ 30, 12.5, mid_z ], [ 65, 12.5, mid_z ]]
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

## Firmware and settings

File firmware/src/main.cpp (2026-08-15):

/**
 * ============================================================================
 *  ESP32 Power Meter — firmware
 * ============================================================================
 *
 *  Reads a PZEM-004T (100 A, Modbus-RTU) energy monitor once a second and
 *  POSTs the readings as JSON to a small ingest server:
 *
 *      POST <server_url>/api/ingest
 *      {"device_id":"powermeter-01","voltage":231.2,"current":1.234,
 *       "power":285.1,"energy":12.345,"frequency":50.0,"pf":0.95,
 *       "rssi":-61,"uptime_s":12345}
 *
 *  Any PZEM value that could not be read is sent as JSON null.
 *
 *  Wiring (see README.md for the full table and the reasons).
 *  NOTE THE CROSS-OVER on the data pair — TX goes to RX, not to TX:
 *      PZEM "TX" -> GPIO4            LED    -> GPIO2 -> 220R -> LED -> GND
 *      PZEM "RX" -> GPIO25           BUTTON -> GPIO13 to GND (INPUT_PULLUP)
 *      PZEM GND -> GND
 *      PZEM 5V  -> the ESP32's 3V3 pin, NOT 5V. That header pin only feeds the
 *                  optocoupler LEDs, and it sets the logic level of the PZEM's
 *                  TX line: fed 5 V, TX idles at 5 V and overdrives the ESP32,
 *                  whose GPIOs top out at 3.6 V. Fed 3.3 V, both directions are
 *                  natively 3.3 V and need no level shifter.
 *
 *  LED status codes:
 *      fast blink  (150 ms)  config/pairing portal is open
 *      medium blink(500 ms)  connecting to WiFi
 *      solid ON              WiFi OK + server reachable
 *      slow blink  (1200 ms) WiFi OK but 2+ consecutive POSTs failed
 *      5 rapid flashes       factory reset triggered, rebooting into portal
 *
 *  Button (GPIO13): hold >= 5 s to erase the WiFi credentials and reboot
 *  into the pairing portal. Server URL / API key / device-id are kept in
 *  NVS and prefilled in the portal.
 *
 *  First boot: the device opens an open access point "PowerMeter-Setup".
 *  Join it and browse to http://192.168.4.1 to pick your WiFi network and
 *  enter the server URL, API key and device id.
 *
 *  Libraries (Arduino IDE Library Manager names):
 *      WiFiManager    by tzapu           (^2.x)
 *      PZEM-004T-v30  by Jakub Mandula   (^1.1.2)
 *      ArduinoJson    by Benoit Blanchon (^7)
 * ============================================================================
 */

#include <Arduino.h>
#include <WiFi.h>
#include <WiFiManager.h>   // tzapu/WiFiManager
#include <HTTPClient.h>
#include <WiFiClientSecure.h>  // HTTPS transport for remote/cellular use
#include <Preferences.h>   // NVS key/value storage (built into the ESP32 core)
#include <PZEM004Tv30.h>   // mandulaj/PZEM-004T-v30
#include <ArduinoJson.h>   // bblanchon/ArduinoJson v7
#include <Ticker.h>        // built-in: lets the LED blink even while
                           // WiFiManager blocks in the config portal

// ----------------------------------------------------------------------------
// Pin assignments — MUST match the wiring table in README.md
// ----------------------------------------------------------------------------
#if defined(CONFIG_IDF_TARGET_ESP32C3)
// ---- ESP32-C3 ----------------------------------------------------------
// The C3 is a different chip, not a smaller ESP32, and three things force a
// different pinout. Verified against the installed SDK, not assumed:
//   * SOC_UART_NUM is 2, so there is no Serial2 at all -- only Serial0/Serial1.
//   * SOC_GPIO_PIN_COUNT is 22, so GPIO25 and GPIO13 simply do not exist.
//   * GPIO2, GPIO8 and GPIO9 are strapping pins (GPIO9 is the BOOT button on
//     most devkits), and GPIO18/19 are the USB Serial/JTAG lines.
// The pins below avoid all of those. Note the onboard LED on a C3 devkit is an
// addressable RGB on GPIO8, not a plain one, so wire your own to GPIO3.
#define PZEM_SERIAL Serial1
static const int PIN_LED     = 3;   // external LED (onboard is RGB on GPIO8)
static const int PIN_BUTTON  = 10;  // factory-reset button to GND, INPUT_PULLUP
static const int PIN_UART_RX = 4;   // ESP32 receives here  <- wire to PZEM "TX"
static const int PIN_UART_TX = 5;   // ESP32 transmits here -> wire to PZEM "RX"

#else
// ---- classic ESP32 (WROOM-32 etc.) --------------------------------------
#define PZEM_SERIAL Serial2
static const int PIN_LED     = 2;   // status LED (onboard LED on most devkits)
static const int PIN_BUTTON  = 13;  // factory-reset button to GND, INPUT_PULLUP
// UART2 for the PZEM. NOT GPIO16/17, the classic choice: those are wired to the
// PSRAM on every WROVER, on -N*R2 WROOM variants and on PICO-D4, where using
// them either fails silently or crashes. GPIO4/25 are free on every ESP32
// module, and are Espressif's own UART2 defaults from arduino-esp32 3.x onward.
// Named from the ESP32's point of view, and deliberately not "PIN_PZEM_RX/TX":
// that reads like "the PZEM's RX pin" and invites wiring TX to TX, which is the
// single most common reason a PZEM never answers.
//   THE DATA LINES CROSS. Wire each one to the OPPOSITE label on the PZEM:
static const int PIN_UART_RX = 4;   // ESP32 receives here  <- wire to PZEM "TX"
static const int PIN_UART_TX = 25;  // ESP32 transmits here -> wire to PZEM "RX"
#endif

// ----------------------------------------------------------------------------
// Behaviour constants
// ----------------------------------------------------------------------------
// Default reporting cadence. Configurable at runtime in the pairing portal,
// because the right value differs enormously by transport — see the floors
// below and the data table in README.md.
static const uint32_t REPORT_INTERVAL_MS   = 1000;   // default: post every 1 s

// Minimum permitted interval, per transport. Not one flat bound, on purpose:
//   http  -> 1 s. Local network, ~700 bytes a post, costs nothing. Keep it.
//   https -> 10 s. Remote/cellular. Even WITH keep-alive a post is ~700 bytes,
//            and every dropped connection costs another ~4.3 KB handshake. At
//            1 s over HTTPS this device would burn roughly 16 GB a month, which
//            would quietly destroy a phone data plan. The floor is a guardrail,
//            not a preference: 30-60 s is the sensible cellular setting.
static const uint32_t MIN_INTERVAL_HTTP_MS  = 1000;
static const uint32_t MIN_INTERVAL_HTTPS_MS = 10000;
static const uint32_t MAX_INTERVAL_MS       = 3600000UL;   // 1 hour

// TLS budgets. A P-384 handshake takes seconds, so the 700 ms plain-HTTP budget
// cannot cover it — every HTTPS POST would time out before it finished.
static const uint32_t TLS_CONNECT_TIMEOUT_MS = 8000;
static const uint32_t TLS_HANDSHAKE_TIMEOUT_S = 10;  // SECONDS on both cores
// Connect and read timeouts apply back-to-back, so the worst case for a dead
// server is 2 x this. Keep it under the report interval so an unreachable
// server slows the cadence a little instead of derailing it.
static const uint32_t HTTP_TIMEOUT_MS      = 700;    // per-request budget
// Counted in failed POSTs, but what matters is the time it represents: 4 at the
// 1 s cadence is ~4 s of trouble, the same as 2 was at the old 2 s cadence. Any
// lower and the LED flickers on every transient blip.
static const int      FAILS_BEFORE_WARNING = 4;      // 4+ fails -> slow blink
static const uint32_t BUTTON_HOLD_MS       = 5000;   // hold time for reset
static const uint32_t BUTTON_DEBOUNCE_MS   = 30;     // contact-bounce filter
static const uint32_t WIFI_NUDGE_MS        = 15000;  // reconnect() retry pace
static const uint32_t WIFI_CONNECT_TIMEOUT_S = 20;   // per connect attempt
static const uint32_t WIFI_BOOT_RETRY_MS   = 3000;   // pause between boot
                                                     // connect attempts; we
                                                     // retry saved credentials
                                                     // forever, never giving up
static const uint32_t BUTTON_POLL_MS       = 10;     // button sampling period
// If handleButton() has not run for longer than this, something blocked and we
// cannot trust the press state we last saw — see the resync there. Must stay
// comfortably below BUTTON_HOLD_MS.
static const uint32_t BUTTON_STARVE_MS     = 250;

// LED blink half-periods (ms) from the status-code table
static const uint32_t BLINK_PORTAL_MS     = 150;
static const uint32_t BLINK_CONNECTING_MS = 500;
static const uint32_t BLINK_NO_SERVER_MS  = 1200;

// Declared up here, ahead of everything else, on purpose. The Arduino IDE
// auto-generates function prototypes and inserts them above the first
// declaration in the file -- so any user-defined type used in a function
// signature must exist before that point, or the .ino fails to compile with
// "LedMode was not declared in this scope" while the identical code builds
// fine under PlatformIO.
enum LedMode : uint8_t {
  LED_OFF,
  LED_SOLID,             // WiFi OK + server reachable
  LED_BLINK_PORTAL,      // config/pairing portal open   (150 ms)
  LED_BLINK_CONNECTING,  // connecting to WiFi           (500 ms)
  LED_BLINK_NO_SERVER,   // WiFi OK, server unreachable  (1200 ms)
};

static const char *AP_NAME           = "PowerMeter-Setup";
static const char *NVS_NAMESPACE     = "powermeter";
static const char *DEFAULT_DEVICE_ID = "powermeter-01";

// ----------------------------------------------------------------------------
// Globals
// ----------------------------------------------------------------------------

// The PZEM-004T "100 A" unit speaks the same Modbus-RTU protocol as the v3.0,
// so this library drives it fine. The constructor starts Serial2 at 9600 baud
// on the given pins.
// Trust anchors for the HTTPS path. BOTH ISRG roots are embedded on purpose.
//
// Let's Encrypt currently serves: leaf <- YE2 <- Root YE <- ISRG Root X2,
// where X2 is cross-signed by X1 and X1 itself is never sent. Verified
// against the live server, either root alone validates that chain today --
// but each fails in a different future:
//
//   X1 alone: breaks the day LE stops sending the X2 cross-sign, because
//             nothing in the trust store matches until that 4th cert arrives.
//   X2 alone: breaks if the certificate is ever re-issued as RSA.
//
// Embedding both costs ~2.7 KB and removes both failure modes.
// mbedtls_x509_crt_parse() accepts concatenated PEM blocks.
static const char ROOT_CA_PEM[] PROGMEM =
    // ISRG Root X2 - ECDSA P-384, expires 2040-09-17
    "-----BEGIN CERTIFICATE-----\n"
    "MIICGzCCAaGgAwIBAgIQQdKd0XLq7qeAwSxs6S+HUjAKBggqhkjOPQQDAzBPMQsw\n"
    "CQYDVQQGEwJVUzEpMCcGA1UEChMgSW50ZXJuZXQgU2VjdXJpdHkgUmVzZWFyY2gg\n"
    "R3JvdXAxFTATBgNVBAMTDElTUkcgUm9vdCBYMjAeFw0yMDA5MDQwMDAwMDBaFw00\n"
    "MDA5MTcxNjAwMDBaME8xCzAJBgNVBAYTAlVTMSkwJwYDVQQKEyBJbnRlcm5ldCBT\n"
    "ZWN1cml0eSBSZXNlYXJjaCBHcm91cDEVMBMGA1UEAxMMSVNSRyBSb290IFgyMHYw\n"
    "EAYHKoZIzj0CAQYFK4EEACIDYgAEzZvVn4CDCuwJSvMWSj5cz3es3mcFDR0HttwW\n"
    "+1qLFNvicWDEukWVEYmO6gbf9yoWHKS5xcUy4APgHoIYOIvXRdgKam7mAHf7AlF9\n"
    "ItgKbppbd9/w+kHsOdx1ymgHDB/qo0IwQDAOBgNVHQ8BAf8EBAMCAQYwDwYDVR0T\n"
    "AQH/BAUwAwEB/zAdBgNVHQ4EFgQUfEKWrt5LSDv6kviejM9ti6lyN5UwCgYIKoZI\n"
    "zj0EAwMDaAAwZQIwe3lORlCEwkSHRhtFcP9Ymd70/aTSVaYgLXTWNLxBo1BfASdW\n"
    "tL4ndQavEi51mI38AjEAi/V3bNTIZargCyzuFJ0nN6T5U6VR5CmD1/iQMVtCnwr1\n"
    "/q4AaOeMSQ+2b1tbFfLn\n"
    "-----END CERTIFICATE-----\n"
    // ISRG Root X1 - RSA 4096, expires 2035-06-04
    "-----BEGIN CERTIFICATE-----\n"
    "MIIFazCCA1OgAwIBAgIRAIIQz7DSQONZRGPgu2OCiwAwDQYJKoZIhvcNAQELBQAw\n"
    "TzELMAkGA1UEBhMCVVMxKTAnBgNVBAoTIEludGVybmV0IFNlY3VyaXR5IFJlc2Vh\n"
    "cmNoIEdyb3VwMRUwEwYDVQQDEwxJU1JHIFJvb3QgWDEwHhcNMTUwNjA0MTEwNDM4\n"
    "WhcNMzUwNjA0MTEwNDM4WjBPMQswCQYDVQQGEwJVUzEpMCcGA1UEChMgSW50ZXJu\n"
    "ZXQgU2VjdXJpdHkgUmVzZWFyY2ggR3JvdXAxFTATBgNVBAMTDElTUkcgUm9vdCBY\n"
    "MTCCAiIwDQYJKoZIhvcNAQEBBQADggIPADCCAgoCggIBAK3oJHP0FDfzm54rVygc\n"
    "h77ct984kIxuPOZXoHj3dcKi/vVqbvYATyjb3miGbESTtrFj/RQSa78f0uoxmyF+\n"
    "0TM8ukj13Xnfs7j/EvEhmkvBioZxaUpmZmyPfjxwv60pIgbz5MDmgK7iS4+3mX6U\n"
    "A5/TR5d8mUgjU+g4rk8Kb4Mu0UlXjIB0ttov0DiNewNwIRt18jA8+o+u3dpjq+sW\n"
    "T8KOEUt+zwvo/7V3LvSye0rgTBIlDHCNAymg4VMk7BPZ7hm/ELNKjD+Jo2FR3qyH\n"
    "B5T0Y3HsLuJvW5iB4YlcNHlsdu87kGJ55tukmi8mxdAQ4Q7e2RCOFvu396j3x+UC\n"
    "B5iPNgiV5+I3lg02dZ77DnKxHZu8A/lJBdiB3QW0KtZB6awBdpUKD9jf1b0SHzUv\n"
    "KBds0pjBqAlkd25HN7rOrFleaJ1/ctaJxQZBKT5ZPt0m9STJEadao0xAH0ahmbWn\n"
    "OlFuhjuefXKnEgV4We0+UXgVCwOPjdAvBbI+e0ocS3MFEvzG6uBQE3xDk3SzynTn\n"
    "jh8BCNAw1FtxNrQHusEwMFxIt4I7mKZ9YIqioymCzLq9gwQbooMDQaHWBfEbwrbw\n"
    "qHyGO0aoSCqI3Haadr8faqU9GY/rOPNk3sgrDQoo//fb4hVC1CLQJ13hef4Y53CI\n"
    "rU7m2Ys6xt0nUW7/vGT1M0NPAgMBAAGjQjBAMA4GA1UdDwEB/wQEAwIBBjAPBgNV\n"
    "HRMBAf8EBTADAQH/MB0GA1UdDgQWBBR5tFnme7bl5AFzgAiIyBpY9umbbjANBgkq\n"
    "hkiG9w0BAQsFAAOCAgEAVR9YqbyyqFDQDLHYGmkgJykIrGF1XIpu+ILlaS/V9lZL\n"
    "ubhzEFnTIZd+50xx+7LSYK05qAvqFyFWhfFQDlnrzuBZ6brJFe+GnY+EgPbk6ZGQ\n"
    "3BebYhtF8GaV0nxvwuo77x/Py9auJ/GpsMiu/X1+mvoiBOv/2X/qkSsisRcOj/KK\n"
    "NFtY2PwByVS5uCbMiogziUwthDyC3+6WVwW6LLv3xLfHTjuCvjHIInNzktHCgKQ5\n"
    "ORAzI4JMPJ+GslWYHb4phowim57iaztXOoJwTdwJx4nLCgdNbOhdjsnvzqvHu7Ur\n"
    "TkXWStAmzOVyyghqpZXjFaH3pO3JLF+l+/+sKAIuvtd7u+Nxe5AW0wdeRlN8NwdC\n"
    "jNPElpzVmbUq4JUagEiuTDkHzsxHpFKVK7q4+63SM1N95R1NbdWhscdCb+ZAJzVc\n"
    "oyi3B43njTOQ5yOf+1CceWxG1bQVs5ZufpsMljq4Ui0/1lvh+wjChP4kqKOJ2qxq\n"
    "4RgqsahDYVvTH9w7jXbyLeiNdd8XM2w9U/t7y0Ff/9yi0GE44Za4rF2LN9d11TPA\n"
    "mRGunUHBcnWEvgJBQl9nJEiU0Zsnvgc/ubhPgXRR4Xq37Z0j4r7g1SgEEzwxA57d\n"
    "emyPxgcYxn/eR44/KJ4EBs+lVDR3veyJm+kXQ99b21/+jh5Xos1AnX5iItreGCc=\n"
    "-----END CERTIFICATE-----\n";

// Transport objects. Both are file-scope so the TLS session survives across
// POSTs — see the comment in readAndReport() for why that is mandatory.
static WiFiClientSecure gTlsClient;
static WiFiClient       gPlainClient;
static HTTPClient       gHttp;
static bool             gTlsReady = false;

// Library signature is (port, receivePin, transmitPin) — receive first, both
// from the ESP32's side.
PZEM004Tv30 pzem(PZEM_SERIAL, PIN_UART_RX, PIN_UART_TX);

WiFiManager wm;
Preferences prefs;
Ticker      ledTicker;

// Runtime copies of the persisted settings
String gServerUrl;  // e.g. "http://192.168.1.8:8000" (no trailing slash)
String gApiKey;     // may be empty -> X-API-Key header is omitted
uint32_t gIntervalMs = REPORT_INTERVAL_MS;  // configured cadence, before clamping

// True when the configured server URL is https:// (case-insensitive).
static bool usingHttps() {
  String u = gServerUrl;
  u.toLowerCase();
  return u.startsWith("https://");
}

/**
 * The interval actually used: whatever is configured, clamped to this
 * transport's floor and the global ceiling. Clamping here rather than at save
 * time means the floor follows the URL — switch the same device from the LAN
 * to the remote HTTPS endpoint and its cadence backs off on its own, with no
 * way to accidentally leave it hammering a metered link once a second.
 */
static uint32_t effectiveIntervalMs() {
  uint32_t want = gIntervalMs ? gIntervalMs : REPORT_INTERVAL_MS;
  uint32_t floor_ = usingHttps() ? MIN_INTERVAL_HTTPS_MS : MIN_INTERVAL_HTTP_MS;
  if (want < floor_)         want = floor_;
  if (want > MAX_INTERVAL_MS) want = MAX_INTERVAL_MS;
  return want;
}

/**
 * One-time TLS setup. Cheap, but must happen before the first HTTPS POST.
 *
 * setHandshakeTimeout() is the important one and is easy to miss: it defaults
 * to 120 SECONDS and is completely independent of setConnectTimeout(). Without
 * it, one stalled handshake — trivially common on a flaky hotspot — blocks
 * loop() for two minutes, freezing the button, the LED and the meter reads.
 * The argument is in SECONDS on both cores.
 */
static void setupTls() {
  if (gTlsReady) return;
  gTlsClient.setCACert(ROOT_CA_PEM);
  gTlsClient.setHandshakeTimeout(TLS_HANDSHAKE_TIMEOUT_S);
  gTlsReady = true;
  Serial.printf("[tls] enabled, handshake timeout %us, roots: ISRG X1 + X2\n",
                (unsigned)TLS_HANDSHAKE_TIMEOUT_S);
}

String gDeviceId;   // e.g. "powermeter-01"

// Portal text fields — created in setup() after loading NVS so they can be
// prefilled with the previously saved values.
WiFiManagerParameter *paramServerUrl = nullptr;
WiFiManagerParameter *paramApiKey    = nullptr;
WiFiManagerParameter *paramDeviceId  = nullptr;
WiFiManagerParameter *paramInterval  = nullptr;

int gConsecutiveFailures = 0;  // failed POSTs in a row (any success resets)

// ----------------------------------------------------------------------------
// LED state machine
//
// A Ticker (hardware timer) toggles the LED in the background, so the blink
// codes stay accurate even while WiFiManager blocks inside the config portal
// or during the initial connection attempt.
// ----------------------------------------------------------------------------

static LedMode gLedMode = LED_OFF;

static const char *ledModeName(LedMode m) {
  switch (m) {
    case LED_OFF:              return "OFF";
    case LED_SOLID:            return "SOLID (server reachable)";
    case LED_BLINK_PORTAL:     return "FAST BLINK (portal open)";
    case LED_BLINK_CONNECTING: return "MEDIUM BLINK (connecting to WiFi)";
    case LED_BLINK_NO_SERVER:  return "SLOW BLINK (server unreachable)";
  }
  return "?";
}

// Ticker callback: just flip the LED.
static void ledToggle() { digitalWrite(PIN_LED, !digitalRead(PIN_LED)); }

// Switch the LED to a new mode. Safe to call every loop() pass — it only
// does work (and logs) when the mode actually changes.
static void setLedMode(LedMode mode) {
  if (mode == gLedMode) return;
  gLedMode = mode;

  ledTicker.detach();
  switch (mode) {
    case LED_OFF:              digitalWrite(PIN_LED, LOW);  break;
    case LED_SOLID:            digitalWrite(PIN_LED, HIGH); break;
    case LED_BLINK_PORTAL:     ledTicker.attach_ms(BLINK_PORTAL_MS,     ledToggle); break;
    case LED_BLINK_CONNECTING: ledTicker.attach_ms(BLINK_CONNECTING_MS, ledToggle); break;
    case LED_BLINK_NO_SERVER:  ledTicker.attach_ms(BLINK_NO_SERVER_MS,  ledToggle); break;
  }
  Serial.printf("[led] %s\n", ledModeName(mode));
}

// ----------------------------------------------------------------------------
// Settings (NVS via Preferences, namespace "powermeter")
// ----------------------------------------------------------------------------
static void loadSettings() {
  prefs.begin(NVS_NAMESPACE, /*readOnly=*/false);  // rw so first boot creates it
  gServerUrl = prefs.getString("server_url", "");
  gApiKey    = prefs.getString("api_key", "");
  gDeviceId  = prefs.getString("device_id", DEFAULT_DEVICE_ID);
  gIntervalMs = prefs.getUInt("interval_ms", REPORT_INTERVAL_MS);
  prefs.end();

  // Normalise: no trailing slash, we append "/api/ingest" ourselves.
  while (gServerUrl.endsWith("/")) gServerUrl.remove(gServerUrl.length() - 1);

  Serial.printf("[cfg] server_url = \"%s\"\n", gServerUrl.c_str());
  Serial.printf("[cfg] api_key    = %s\n", gApiKey.isEmpty() ? "(not set)" : "(set, hidden)");
  Serial.printf("[cfg] device_id  = \"%s\"\n", gDeviceId.c_str());
  Serial.printf("[cfg] interval   = %lu ms configured, %lu ms in use (%s floor)\n",
                (unsigned long)gIntervalMs, (unsigned long)effectiveIntervalMs(),
                usingHttps() ? "https" : "http");
}

// Called by WiFiManager when the user hits "Save" in the portal.
// Persists the three custom fields to NVS and updates the runtime copies,
// so no reboot is needed for them to take effect.
static void onPortalSave() {
  gServerUrl = paramServerUrl->getValue();
  gApiKey    = paramApiKey->getValue();
  gDeviceId  = paramDeviceId->getValue();

  // Interval arrives in seconds; 0/blank/garbage falls back to the default
  // rather than producing a busy loop.
  {
    String iv = paramInterval ? String(paramInterval->getValue()) : String("");
    iv.trim();
    uint32_t secs = (uint32_t)iv.toInt();
    gIntervalMs = secs > 0 ? secs * 1000UL : REPORT_INTERVAL_MS;
  }

  gServerUrl.trim();
  gApiKey.trim();
  gDeviceId.trim();
  while (gServerUrl.endsWith("/")) gServerUrl.remove(gServerUrl.length() - 1);
  if (gDeviceId.isEmpty()) gDeviceId = DEFAULT_DEVICE_ID;

  // A blank server URL is never meaningful, and there is no way to set it again
  // at runtime once saved — so treat an empty box as "leave it alone" rather
  // than wiping a working URL. (An empty API key IS meaningful: it means the
  // server has no key configured, so that one stays overwritable.)
  if (gServerUrl.isEmpty()) {
    prefs.begin(NVS_NAMESPACE, /*readOnly=*/true);
    gServerUrl = prefs.getString("server_url", "");
    prefs.end();
    if (!gServerUrl.isEmpty()) {
      Serial.println("[cfg] server URL submitted blank — keeping the saved one");
    }
  }

  prefs.begin(NVS_NAMESPACE, /*readOnly=*/false);
  prefs.putString("server_url", gServerUrl);
  prefs.putString("api_key", gApiKey);
  prefs.putString("device_id", gDeviceId);
  prefs.putUInt("interval_ms", gIntervalMs);
  prefs.end();

  Serial.println("[cfg] portal settings saved to NVS");
  loadSettings();  // re-log the effective values
}

// Called by WiFiManager the moment the config portal opens.
static void onPortalOpened(WiFiManager *w) {
  setLedMode(LED_BLINK_PORTAL);
  Serial.println("[wifi] Config portal open.");
  Serial.printf("[wifi] Join the open AP \"%s\" and browse to http://192.168.4.1\n", AP_NAME);
}
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
void loop() {
  uint32_t now = millis();

  handleButton(now);
  handleWifi(now);

  // Report on the configured cadence, clamped to the floor for this transport.
  static uint32_t lastReportMs = 0;
  if (now - lastReportMs >= effectiveIntervalMs()) {
    lastReportMs = now;
    readAndReport();
  }

  // LED state machine: recompute the desired mode from current status.
  // (Portal mode only exists inside setup(), handled by the AP callback.)
  if (WiFi.status() != WL_CONNECTED) {
    setLedMode(LED_BLINK_CONNECTING);
  } else if (gConsecutiveFailures >= FAILS_BEFORE_WARNING) {
    setLedMode(LED_BLINK_NO_SERVER);
  } else {
    setLedMode(LED_SOLID);
  }
}

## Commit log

2026-08-14 ESP32 power meter: firmware, backend API and dashboard
    Complete monitoring stack for a PZEM-004T (100A) energy meter:
    - firmware/ ESP32 (PlatformIO/Arduino). Reads the PZEM over Modbus-RTU on
    Serial2, pairs over WiFiManager (PowerMeter-Setup AP), POSTs a
    reading every 2 s. Status LED on GPIO2, 5-second-hold factory
    reset button on GPIO13. Server URL/API key/device id persist
    in NVS across a WiFi reset.
    - server/ FastAPI + SQLite. Ingest with optional X-API-Key, plus latest/
    history/stats/health endpoints. SQL bucket downsampling for
    charts, hourly retention sweep, CORS for GitHub Pages. Docker
    Com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
    [main.cpp]
2026-08-14 Add mock device, default backend URL, and drop the settings popup
    - tools/mock_esp32.py: simulates a house (fridge cycling, kettle spikes, AC)
    and posts the firmware's exact payload. --backfill seeds history straight
    into SQLite since the API stamps its own receive time. ~1% of readings go
    out as nulls so the chart gap handling gets exercised.
    - Dashboard reads DEFAULT_BASE_URL when nothing is saved, so it connects on
    load instead of opening settings every visit. The gear button still edits
    it, and a Reset to default button restores the shipped URL. Uses ?? so an
    explicitly cleared field is respected rather than silently refilled.
    - Send ngrok-skip-browser-warning on fetches; fre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
2026-08-14 Publish readings once a second instead of every two
    REPORT_INTERVAL_MS 2000 -> 1000, and the dashboard polls /api/latest at the
    same 1 s pace. Two things had to move with it rather than just the number:
    - HTTP_TIMEOUT_MS 1500 -> 700. Connect and read timeouts apply back-to-back,
    so a dead server could stall a cycle ~3 s — three times the new interval.
    At 700 the worst case is ~1.4 s, and late cycles are skipped not queued.
    - FAILS_BEFORE_WARNING 2 -> 4, to hold the LED's meaning steady: it still
    means roughly 4 s of trouble, not 2 failed requests. At 2 it would flicker
    on any transient blip now that requests are twice as frequent.
    The online threshold stays at 10 s (now ~10 misse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
    [main.cpp]
2026-08-14 Compile the firmware for real; fix flash headroom and a wrong library name
    Built it on both toolchains rather than only reviewing it. Two genuine defects
    surfaced that static review had missed:
    - Flash was at 89% of the stock 1.2 MB app partition. It runs, but leaves
    ~144 KB spare, so almost any addition would overflow it. WiFiManager's
    captive portal is the bulk. This firmware keeps everything in NVS and never
    touches SPIFFS, so board_build.partitions = min_spiffs.csv trades that dead
    filesystem for app space: 59% used, OTA partition still intact.
    - The Arduino Library Manager has no entry named PZEM-004T-v30, so step 2
    of the Arduino IDE instructions could not be followed as wri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
2026-08-14 Retry saved WiFi credentials forever instead of falling into pairing mode
    Reconnection while running was already endless (setAutoReconnect plus a
    reconnect() nudge every 15 s). The boot path was not, and it behaved badly in
    the exact case that matters: a power cut.
    Previously autoConnect() tried the saved network for 20 s and, on failure,
    opened the pairing portal for 300 s. Reading WiFiManager's source confirms
    processConfigPortal() does not retry stored credentials while the portal is up,
    so those 5 minutes were spent making zero connection attempts -- as an open AP,
    with the LED fast-blinking 'needs pairing' when the credentials were in fact
    fine and the router was simply still booting.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
    [main.cpp]
2026-08-14 Fix the button escape hatch, which the retry loop had broken both ways
    Adversarial review of the previous commit (4 lenses against the installed
    WiFiManager 2.0.17 and both ESP32 core sources, each finding then refuted by a
    skeptic pass: 20 raised, 11 survived) found that the endless-retry change had
    quietly disabled the only way back into pairing mode -- the exact escape hatch
    that commit claimed still worked.
    Root cause: the retry loop delegated connecting to wm.autoConnect(), which
    blocks for the whole connect timeout (~20 s against an absent router, proven via
    WiFiManager.cpp:1135 delay(500) + waitForConnectResult(20000), which exits early
    only on WL_CONNECTED/WL_CONNECT_FAILED while a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
    [main.cpp]
2026-08-14 Add a 3D-printable enclosure: parametric box with a screw-on lid
    OpenSCAD source plus ready-to-slice STLs. Both parts render as watertight
    2-manifold solids and print flat with no supports.
    The requested size was 150 x 100 x 20 mm. The footprint is unchanged but the
    height is 32 mm, because 20 mm does not fit the hardware. The PZEM-004T's
    5.08 mm-pitch screw terminals stand 10.0 mm above the PCB (KF301 drawing), so
    the stack is 5 mm standoff + 1.6 mm PCB + 10 mm terminal = 16.6 mm against a
    16 mm cavity -- over budget before any wiring, and several vendors list the whole
    module at 16-18 mm tall, which would not fit lying flat either. A socketed ESP32
    devkit is 13-18 mm as well. outer_z = 32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
    [box.stl, enclosure.scad, lid.stl]
2026-08-14 Enclosure: seal the box, 4 corner screws, gussets instead of posts
    Three changes, all as requested:
    - No openings. holes_x0/holes_x1 are now empty, so the box prints sealed and you
    drill entries once the boards are placed -- with 2 mm of wall that is seconds
    of work, and the hole ends up where the cable actually lands rather than where
    the model guessed. The parameters and the gland sizing table stay documented
    for anyone who wants them modelled.
    - Four screws, one per corner, down from eight.
    - The screw bosses are no longer free-standing cylinders. Each corner is filled
    solid with a 45-degree gusset running 16 mm along both walls, so the screw
    material is continuous with the s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
    [box.stl, enclosure.scad, lid.stl]
2026-08-14 Enclosure: box prints with no holes at all, not even screw pilots
    The corner gussets are left solid. The box.stl is now a 44-facet solid with zero
    penetrations anywhere: four plain rectangular faces and a rim whose only vertices
    are the four outer corners plus the eight gusset diagonal ends.
    This turns out to be the better assembly method rather than a compromise. The lid
    keeps its four clearance holes, so it doubles as a drill template: sit it on the
    box, drill down through its holes into the gussets, and the two parts physically
    cannot end up misaligned -- which is the usual annoyance with pre-modelled holes
    and a print that shrank half a percent. There is 16 mm of solid plastic under
    eac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
    [box.stl, enclosure.scad, lid.stl]
2026-08-14 Enclosure: switch to M2 and cut 70% of the plastic out of the gussets
    M2 x 12 mm, four corners. With the 3 mm lid that is ~9 mm of thread engagement.
    Clearance holes 2.4 mm, counterbore resized to 4.2 x 1.4 for an M2 pan head, and
    the drill guidance is now 1.8 mm in PLA / 1.7 in PETG-ABS-ASA / 1.6 in nylon --
    still above the textbook 1.6 for M2, because in a printed part the layers give a
    tight pilot a plane to split along.
    The gussets shrink twice over:
    - Footprint 16 -> 12 mm, with the screw moved from 5 to 4 mm in. M2 needs far
    less material than M3: that leaves 1.95 mm around the pilot out to the
    diagonal face, above the ~1.5 mm thread-forming into plastic wants. Smaller
    than thi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
    [box.stl, enclosure.scad, lid.stl]
2026-08-14 Enclosure: resize to 100 x 80 x 30 mm
    Cavity is now 96 x 76 x 25 mm. Checked the hardware still fits before changing
    anything, because the footprint drop is significant:
    PZEM-004T 74 x 31 mm and ESP32 devkit 55 x 28 mm, side by side with their long
    axes along the 96 mm direction: 31 + 28 = 59 mm across the 76 mm width, 17 mm
    spare; longest board 74 mm along the 96 mm length.
    Turned the other way the PZEM's 74 mm length would have only 76 mm to sit in,
    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
    [box.stl, enclosure.scad, lid.stl]
2026-08-14 Firmware: correct an unsafe wiring instruction and move UART2 off the PSRAM pins
    Two hardware problems, both found by verifying claims against primary sources
    rather than repeating them.
    1. The README told you to power the PZEM's 4-pin header from 5 V while also
    asserting "its UART logic side works fine at 3.3 V TTL, so no level shifter
    needed". That combination is wrong and over-stresses the ESP32.
    The TTL section of a PZEM-004T contains no regulator and no level
    translation -- just a connector, four 1 kOhm resistors and two optocouplers.
    The opto output is open-collector with R4, a 1 kOhm pull-up to the header's
    supply pin, so whatever feeds that pin becomes the logic l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
    [main.cpp]
2026-08-14 Firmware: rename the UART pin constants so the cross-over cannot be misread
    A user wired PZEM TX to the ESP32's TX and PZEM RX to its RX. Harmless, but no
    communication -- and the naming in this file invited it. PIN_PZEM_RX reads like
    "the PZEM's RX pin", when it is actually the pin the ESP32 receives on, which
    must be wired to the PZEM's TX.
    Renamed to PIN_UART_RX / PIN_UART_TX, named unambiguously from the ESP32's side,
    with a comment stating the cross-over and why the old names were dropped. No
    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
2026-08-15 Deploy the backend to the home server; dashboard points at it over HTTPS
    Backend now runs on the dilanp home server at /opt/stacks/powermeter, following
    the same convention as the other 18 stacks there. Docker Compose, SQLite
    persisted to ./data, restart: unless-stopped, .env at mode 600 with a generated
    API key. Verified on the box: health OK, ingest rejects a missing key with 401
    and accepts a valid one, /api/latest reads back correctly.
    Published through the existing Nginx Proxy Manager as proxy host 19,
    powermeter.dilanp.duckdns.org -> http://192.168.1.8:8000, added via NPM's own
    API rather than by editing its database, so it stays manageable from the UI and
    the other 18 hosts were neve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
2026-08-15 Add a script to generate the Arduino IDE sketch folder
    The IDE needs a folder X containing X.ino, which does not match the
    src/main.cpp layout PlatformIO uses. Generating it on demand keeps
    src/main.cpp as the single source of truth, rather than committing a second
    copy of the firmware that would silently drift out of sync with the first.
    Prints the Arduino IDE settings alongside it, since the partition scheme is
    the one setting that is not optional: on the default 1.2 MB app partition this
    build lands at 89% full.
2026-08-15 Docs: make the two-URL split prominent
    The server URL is configured at runtime through the pairing portal rather than
    compiled in, and the ESP32 must use the plain-http LAN address, not the public
    HTTPS one. Both facts were already documented, but as a sub-bullet inside the
    pairing steps, which is not where someone looks when they open the sketch and
    cannot find their domain in it.
    Now a callout with the reasoning: it lives in NVS so the server can move without
    a reflash; the firmware has no TLS at all (plain HTTPClient, no
    WiFiClientSecure) so an https URL fails every POST and parks the LED on the
    server-unreachable blink; and the backend has two consumers with genuinely
    different needs --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
2026-08-15 Add HTTPS so the meter can report from remote sites over a phone hotspot
    The firmware had no TLS at all, so it could only reach the backend on the LAN.
    It now picks its transport from the configured URL scheme: plain HTTP on the
    LAN as before, TLS when the URL is https. Costs +3.4 KB of flash, because ~69 KB
    of mbedTLS was already linked into the binary.
    Verified against the live server rather than assumed, and three things came back
    different from what I expected:
    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
2026-08-15 Support ESP32-C3
    The same source now builds for both chips, switching pins on
    CONFIG_IDF_TARGET_ESP32C3. Tried it as-is first and it failed immediately on
    'Serial2 was not declared' -- the C3 is not a smaller ESP32, and three facts
    checked against the installed SDK force a different pinout:
    SOC_UART_NUM is 2 -> no Serial2 at all, only Serial0/Serial1
    SOC_GPIO_PIN_COUNT is 22 -> GPIO25 and GPIO13 do not exist
    GPIO2/8/9 are strapping -> GPIO9 is BOOT on most devkits; 18/19 are USB JTAG
    C3 pins: PZEM TX->GPIO4, RX->GPIO5, LED->GPIO3, button->GPIO10, on Serial1.
    Also worth knowing: a C3 devkit's onboard LED is an addressable RGB on GPIO8,
    so digitalWrite cannot drive it and an ext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
    [main.cpp]
